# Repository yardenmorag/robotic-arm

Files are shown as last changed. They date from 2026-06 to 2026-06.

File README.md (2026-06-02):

# 7-Servo 3D-Printed Robotic Arm

A custom-built robotic arm designed, 3D-printed, wired, and programmed as a hands-on robotics and mechatronics project.
The arm is controlled by an **ESP32** using a **PCA9685 16-channel PWM servo driver**. It uses seven servo motors to control the base, arm segments, wrist, and gripper.

## Project Overview

The goal of this project is to build a lightweight robotic arm capable of controlled joint movement and eventually position-based control using forward and inverse kinematics.
This project combines:

* Mechanical design and 3D printing
* Servo motor actuation
* ESP32 embedded control
* External power distribution
* Multi-joint motion control
* Future kinematics and simulation development

## Features

* 7 servo-controlled joints
* 3D-printed mechanical structure
* ESP32-based control system
* PCA9685 PWM servo driver for stable multi-servo control
* External 5 V power supply for the motors
* Smooth servo movement implementation
* Adjustable joint positions through code
* Designed for future inverse kinematics control

## Degrees of Freedom

The robotic arm includes the following controlled movements:

| Joint | Function | Servo Motor |
| --- | --- | --- |
| Base | Rotates the entire arm | DS3225 |
| Lower Arm | Lifts the lower arm from the base | DS3225 |
| Elbow | Controls elbow lifting motion | MG996R |
| Upper Arm | Lifts the upper arm segment | MG996R |
| Wrist Pitch | Moves the wrist up and down | MG90S |
| Wrist Roll  | Rotates the wrist | MG90S |
| Gripper | Opens and closes the gripper | MG90S |

## Hardware

### Electronics

| Component | Description |
| --- | --- |
| ESP32 | Main microcontroller |
| PCA9685 | 16-channel PWM servo driver |
| Mean Well LRS-75-5 | External 5 V power supply |
| DS3225 Servo ×2 | High-torque servos for the heavier lower joints |
| MG996R Servo ×2 | Medium/high-torque servos for the arm joints |
| MG90S Servo ×3 | Small servos for the wrist and gripper |

### Mechanical Parts

* Custom 3D-printed robotic arm structure
* 3D-printed arm links
* 3D-printed wrist assembly
* 3D-printed gripper
* Servo mounting brackets and joint connectors

## Servo Channel Mapping

The PCA9685 channels are mapped as follows:

| PCA9685 Channel | Joint |
| --- | --- |
| 0 | Base rotation |
| 1 | Lower arm lift |
| 2 | Elbow lift |
| 3 | Upper arm lift |
| 4 | Wrist pitch |
| 5 | Wrist roll |
| 6 | Gripper open/close |

Example mapping in code:

```cpp
const int baseChannel = 0;
const int lowerArmChannel = 1;
const int elbowChannel = 2;
const int upperArmChannel = 3;
const int wristPitchChannel = 4;
const int wristRollChannel = 5;
const int gripperChannel = 6;
```

## Wiring Overview

### PCA9685 to ESP32

| PCA9685 Pin | ESP32 Pin |
| --- | --- |
| SDA | GPIO 21 |
| SCL | GPIO 22 |
| GND | GND |
| VCC | ESP32 logic power |

### Servo Power

The servos are powered using an external 5 V power supply rather than directly from the ESP32.

Important wiring notes:

* The servo power supply is connected to the PCA9685 `V+` terminal.
* The ESP32 ground and external power supply ground must be connected together.
* The ESP32 should not directly power all of the servos.
* High-torque servos can draw significant current, especially under load.

## Software

The arm is controlled using Arduino-compatible C++ code running on the ESP32.

### Main Libraries

* `Wire.h`
* `Adafruit_PWMServoDriver.h`

### Control Method

The PCA9685 board generates PWM signals for each servo. Joint positions are controlled by sending target angles that are converted into PWM pulse values.

The software includes smooth movement behavior so that the servos move gradually toward their target positions instead of instantly jumping between angles.

## Example Starting Pose

An example initial joint pose used during development:

```cpp
int startPose[] = {
    95,  // Base
    0,   // Lower arm
    0,   // Elbow
    0,   // Upper arm
    90,  // Wrist pitch
    90,  // Wrist roll
    90   // Gripper
};
```

Actual safe angle ranges may vary depending on the mechanical design and servo installation orientation.

## Project Structure

```text
robotic-arm/
├── code/                # ESP32 / Arduino control code
├── cad/                 # 3D models and mechanical design files
├── images/              # Project photos and diagrams
├── simulation/          # Future kinematics or MATLAB simulation files
└── README.md
```

The repository structure can be adjusted depending on the files included in the project.

## Current Status

Completed:

* Mechanical arm design and assembly
* 3D-printed structure
* Servo installation
* ESP32 and PCA9685 control setup
* External servo power system
* Basic multi-joint movement
* Smooth servo motion testing

In development:

* Joint calibration and motion refinement
* Improved torque and mechanical stability
* Forward kinematics
* Inverse kinematics
* Simulation-based control
* Position-based end-effector movement

## Challenges Encountered

During development, several practical robotics challenges were explored:

* Providing enough torque for the heavier arm joints
* Reducing servo jitter at the end of movements
* Powering multiple servos safely
* Maintaining a common electrical ground between the controller and power supply
* Matching servo movement directions with the mechanical design
* Planning the transition from direct joint control to inverse kinematics

## Future Improvements

Planned improvements include:

* Implementing forward kinematics
* Implementing inverse kinematics for XYZ position control
* Integrating a simulation model of the arm
* Improving the mechanical rigidity of the joints
* Reducing play and vibration in the printed structure
* Adding manual control through a joystick or graphical interface
* Developing basic pick-and-place movement sequences

## Images and Demonstration

Add project images or videos here once available.

Example:

```md
![Robotic Arm Assembly](images/robotic-arm.jpg)
```

A demonstration video can also be linked here in the future.

## Learning Goals

This project was built as part of a personal learning journey in robotics and mechanical engineering. It provides practical experience in:

* Mechanical CAD design
* 3D printing
* Servo motor selection
* Embedded programming
* Power electronics and wiring
* Multi-joint robotics
* Robotic arm kinematics

## Author

**Yarden Morag**

Mechanical Engineering Student
Interested in robotics, mechatronics, and biomimetic mechanical design.

## License

This project is currently intended for educational and personal development purposes.

A formal open-source license can be added in the future.

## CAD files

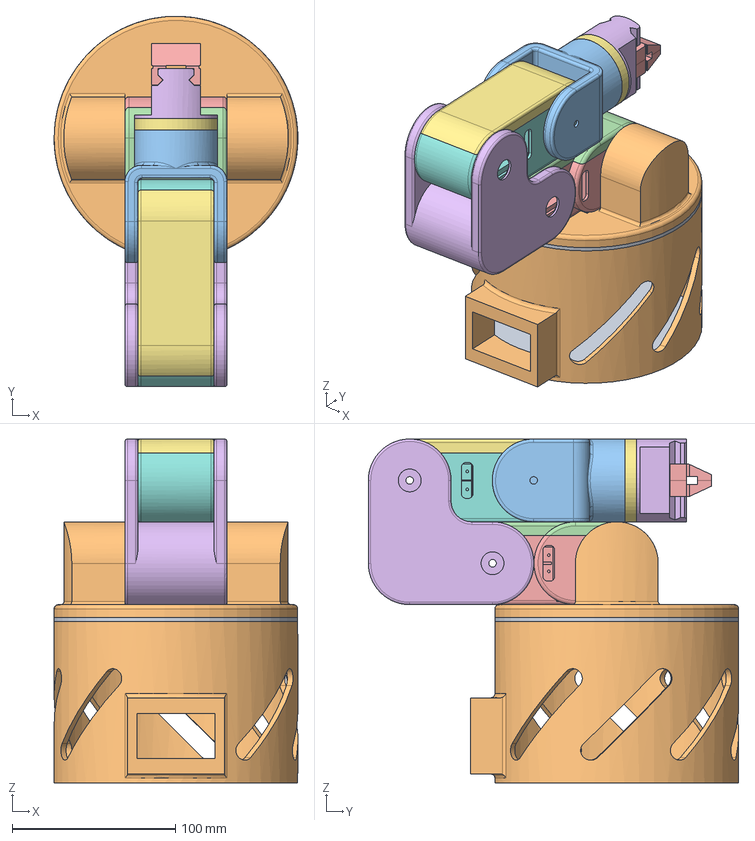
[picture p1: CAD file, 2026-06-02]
CAD files/fusion 360/Mark 1 Assembly.step
149.4 x 226.9 x 210.8 mm

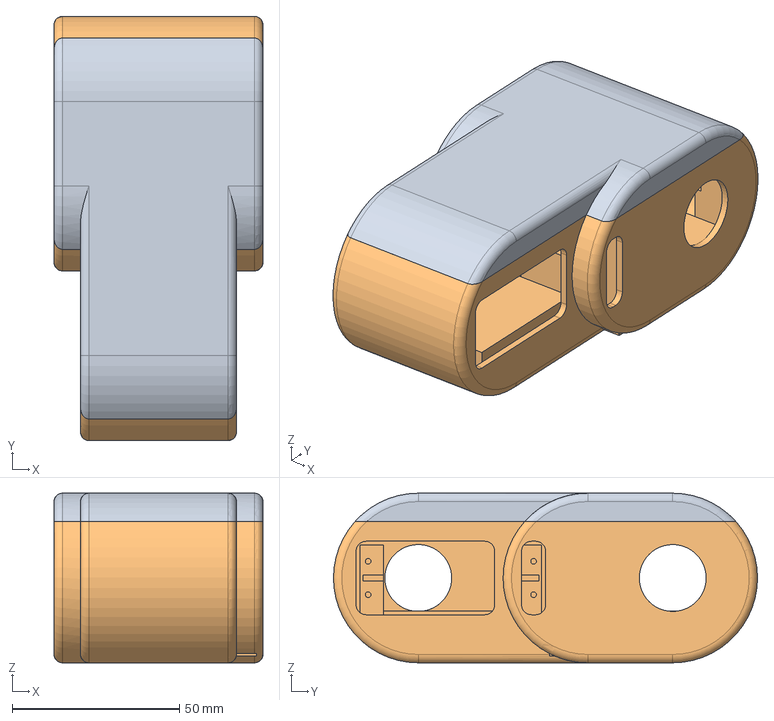
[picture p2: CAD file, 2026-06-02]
CAD files/fusion 360/Lower arm.step
62.5 x 126.9 x 50.8 mm

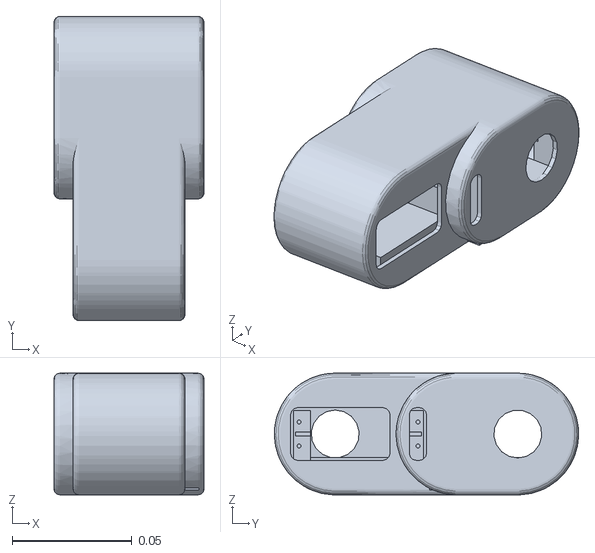
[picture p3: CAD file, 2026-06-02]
SImulation/URDF_mesh3/meshes/link_2.STL
0.0625 x 0.127 x 0.0507

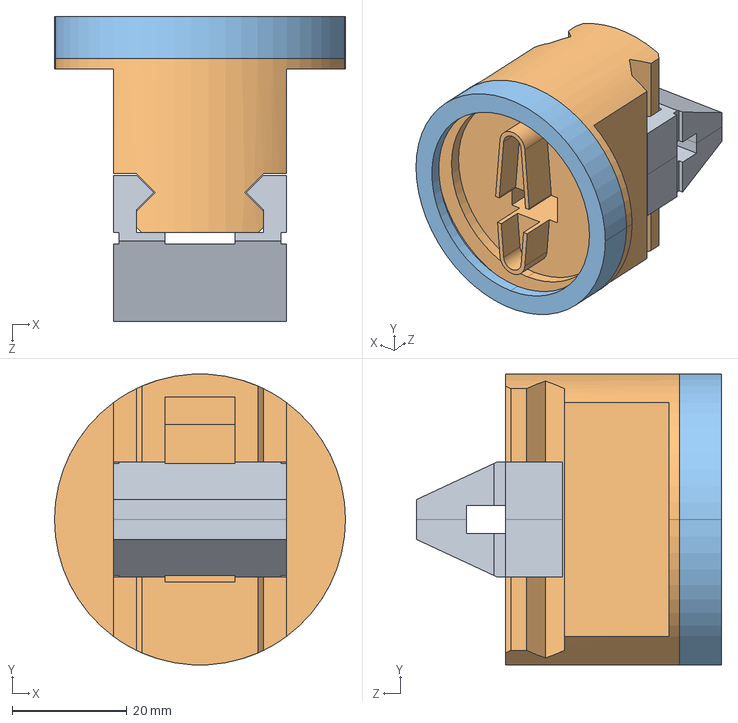
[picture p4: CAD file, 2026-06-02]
SImulation/xml files/Gripper part_Default_sldprt.STEP
50.8 x 50.7 x 53.2 mm

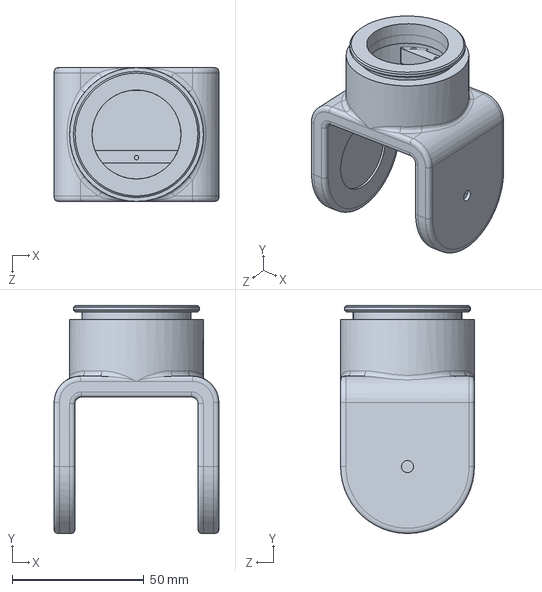
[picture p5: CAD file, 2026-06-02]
CAD files/solidworks/Upper joint.SLDPRT
62.5 x 86.5 x 50.8 mm

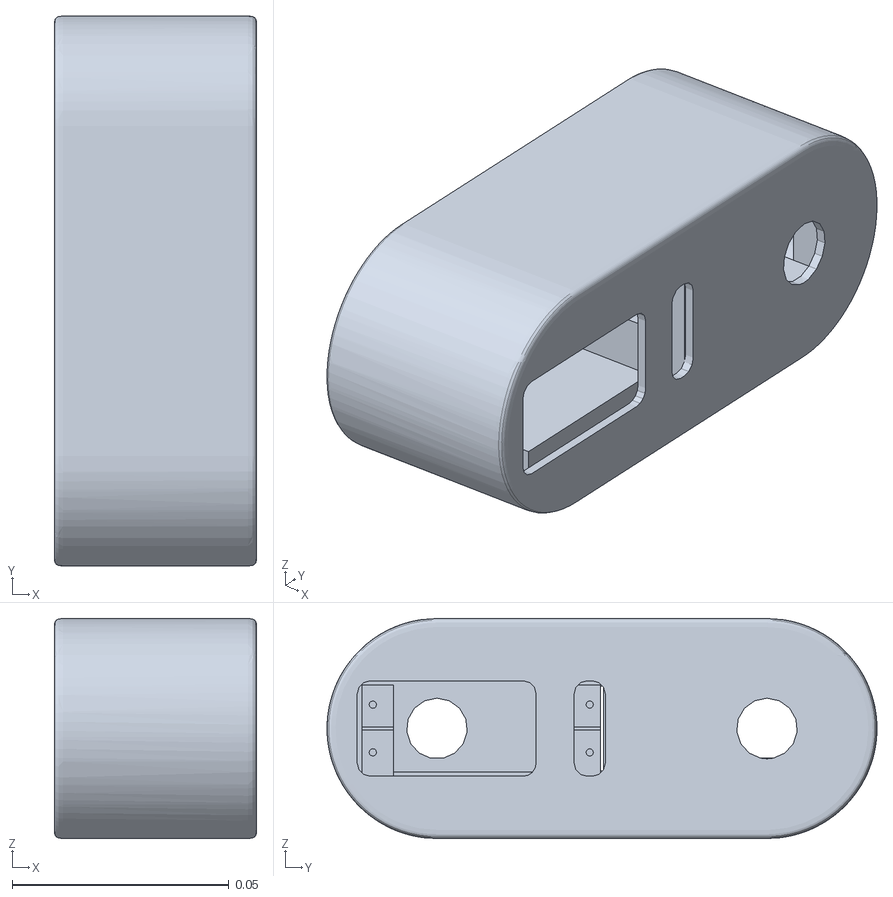
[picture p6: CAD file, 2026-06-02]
SImulation/URDF_mesh3/meshes/link_4.STL
0.0467 x 0.127 x 0.0507

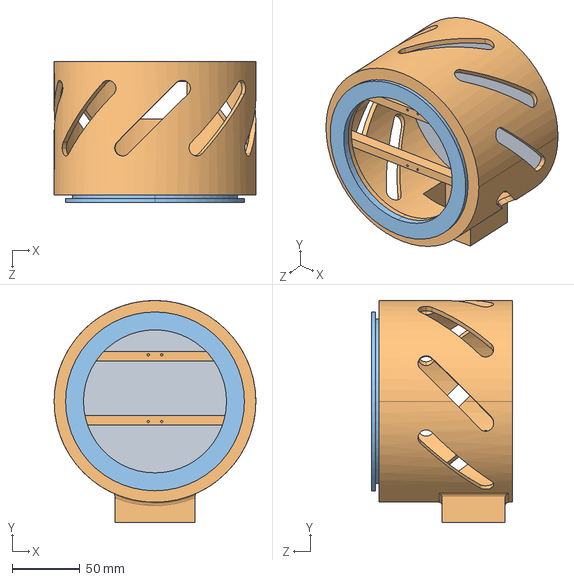
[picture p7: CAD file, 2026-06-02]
SImulation/xml files/Base frame_Default_sldprt.STEP
149.4 x 164.4 x 104.6 mm

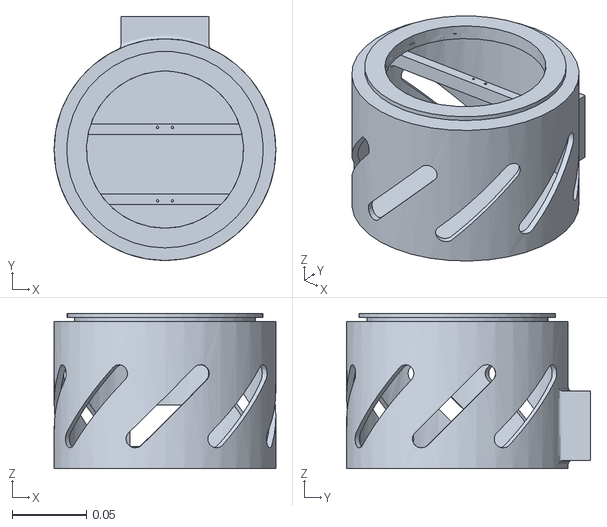
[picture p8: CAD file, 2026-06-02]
SImulation/URDF_mesh3/meshes/base_link.STL
0.149 x 0.164 x 0.105

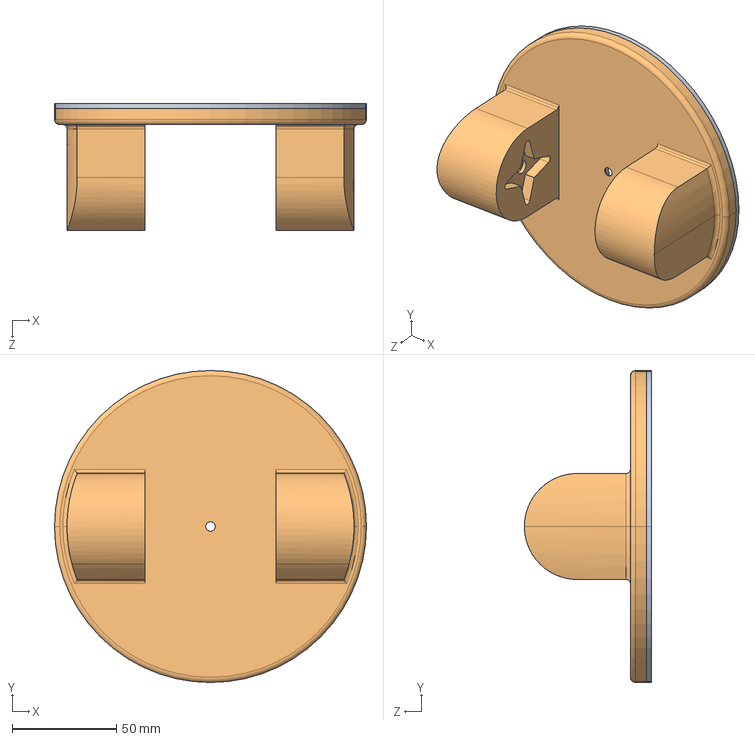
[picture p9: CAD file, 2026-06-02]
SImulation/xml files/Base rotator_Default_sldprt.STEP
149.4 x 149.4 x 60.9 mm

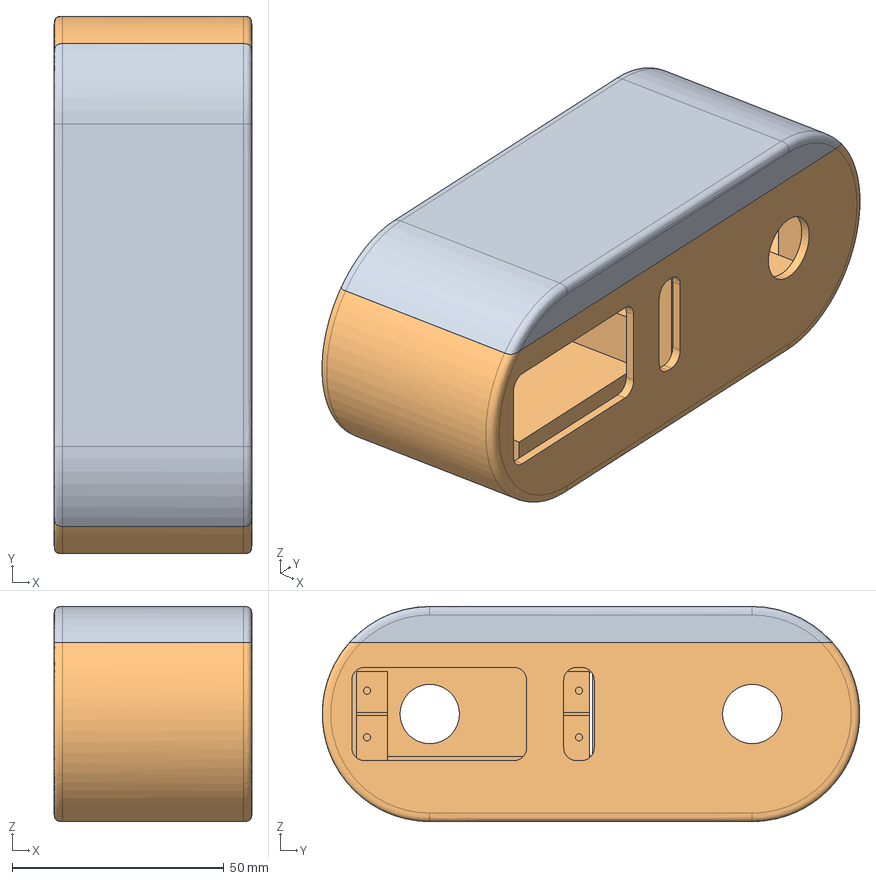
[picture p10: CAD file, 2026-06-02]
CAD files/fusion 360/Upper arm.step
46.7 x 126.9 x 50.8 mm

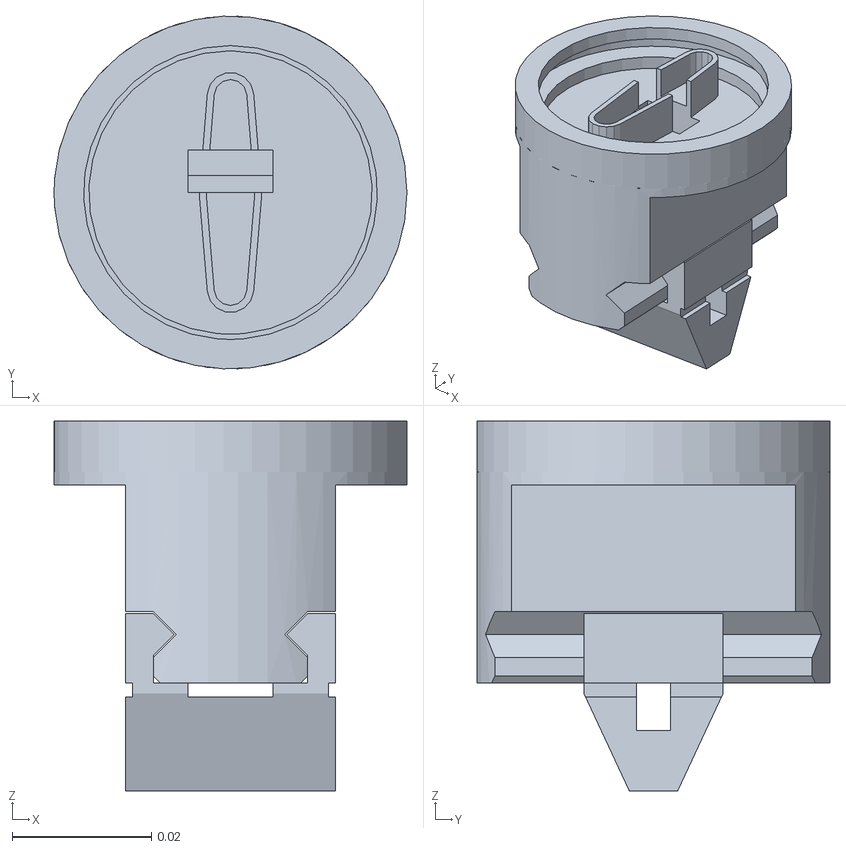
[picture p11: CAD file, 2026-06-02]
SImulation/URDF_mesh3/meshes/link_6.STL
0.0507 x 0.0507 x 0.0532

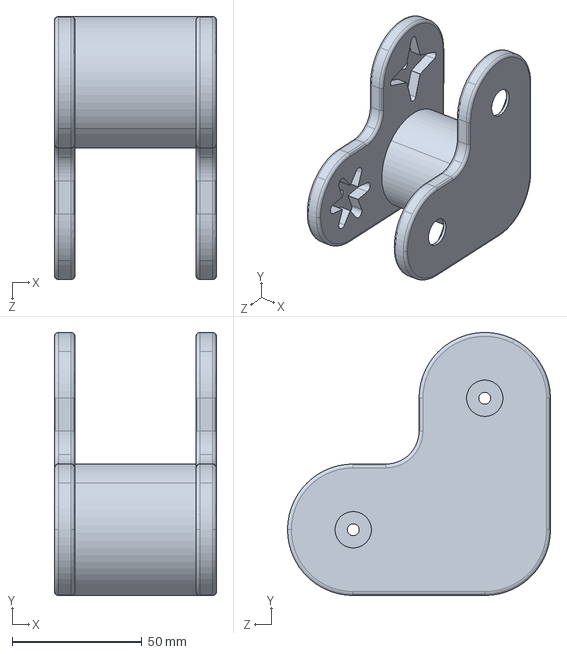
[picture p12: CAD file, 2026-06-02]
SImulation/xml files/Lower joint_Default_sldprt.STEP
62.5 x 101.5 x 101.5 mm

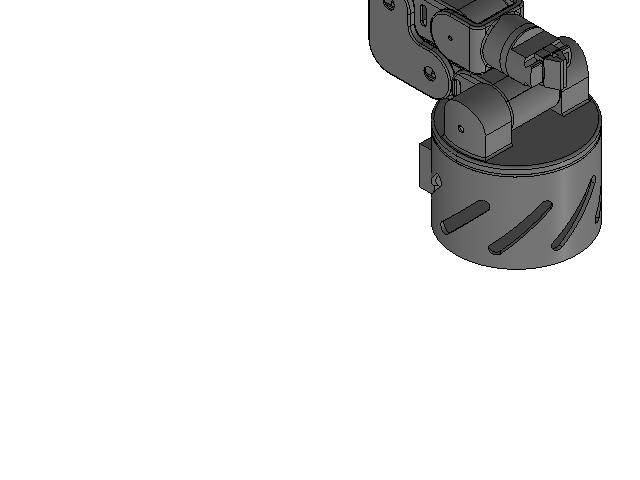
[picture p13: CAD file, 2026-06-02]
CAD files/solidworks/Robot assembly.SLDASM
Base frame
Base rotator
Lower arm
Lower joint
Upper arm
Upper joint
Gripper part

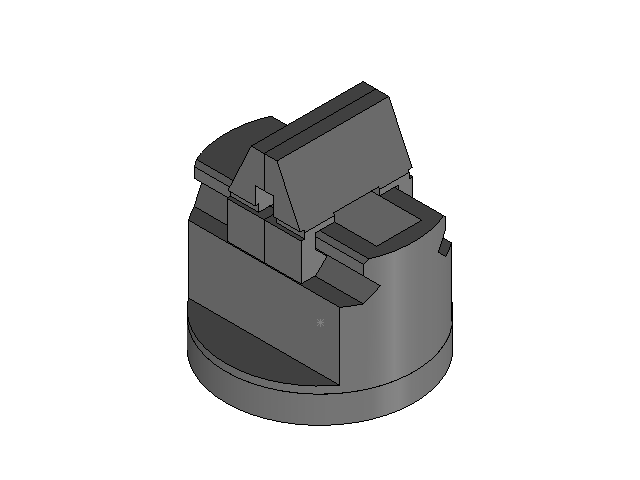
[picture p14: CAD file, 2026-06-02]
CAD files/solidworks/Gripper assmebly.SLDASM
2025-07-12-18-57-27-273.step
2025-07-12-18-57-29-992.step
eBom-FreeParts.step

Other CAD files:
CAD files/fusion 360/Gripper.step
CAD files/fusion 360/Base frame.step
CAD files/solidworks/Gripper part.SLDPRT
CAD files/fusion 360/Base rotator.step
CAD files/fusion 360/Lower joint.step
CAD files/fusion 360/Upper joint.step
CAD files/solidworks/Base frame.SLDPRT
CAD files/solidworks/Base rotator.SLDPRT
CAD files/solidworks/Lower arm.SLDPRT
CAD files/solidworks/Lower joint.SLDPRT
CAD files/solidworks/Upper arm.SLDPRT
SImulation/URDF_mesh3/meshes/link_1.STL
SImulation/URDF_mesh3/meshes/link_3.STL
SImulation/URDF_mesh3/meshes/link_5.STL
SImulation/xml files/Lower arm_Default_sldprt.STEP
SImulation/xml files/Upper arm_Default_sldprt.STEP
SImulation/xml files/Upper joint_Default_sldprt.STEP

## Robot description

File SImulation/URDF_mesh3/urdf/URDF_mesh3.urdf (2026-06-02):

<?xml version="1.0" encoding="utf-8"?>
<!-- This URDF was automatically created by SolidWorks to URDF Exporter! Originally created by Stephen Brawner (brawner@gmail.com) 
     Commit Version: 1.6.0-4-g7f85cfe  Build Version: 1.6.7995.38578
     For more information, please see http://wiki.ros.org/sw_urdf_exporter -->
<robot name="URDF_mesh3">
  <link name="base_link">
    <inertial>
      <origin xyz="-2.88841529450125E-05 0.00680637713324165 0.0542195174122674" rpy="0 0 0" />
      <mass value="0.276769434491233" />
      <inertia ixx="0.000920049908931992" ixy="4.47962690896385E-07" ixz="8.47165923723122E-07" iyy="0.000798308663008452" iyz="5.72343861467879E-05" izz="0.00126720597801514" />
    </inertial>
    <visual>
      <origin xyz="0 0 0" rpy="0 0 0" />
      <geometry>
        <mesh filename="package://URDF_mesh3/meshes/base_link.STL" />
      </geometry>
      <material name="">
        <color rgba="0.627450980392157 0.627450980392157 0.627450980392157 1" />
      </material>
    </visual>
    <collision>
      <origin xyz="0 0 0" rpy="0 0 0" />
      <geometry>
        <mesh filename="package://URDF_mesh3/meshes/base_link.STL" />
      </geometry>
    </collision>
  </link>
  <link name="link_1">
    <inertial>
      <origin xyz="-0.0010669 -5.4441E-06 0.016145" rpy="0 0 0" />
      <mass value="0.10166" />
      <inertia ixx="0.0001764" ixy="2.5396E-10" ixz="1.8796E-06" iyy="0.00023841" iyz="-8.9944E-09" izz="0.00036361" />
    </inertial>
    <visual>
      <origin xyz="0 0 0" rpy="0 0 0" />
      <geometry>
        <mesh filename="package://URDF_mesh3/meshes/link_1.STL" />
      </geometry>
      <material name="">
        <color rgba="0.62745 0.62745 0.62745 1" />
      </material>
    </visual>
    <collision>
      <origin xyz="0 0 0" rpy="0 0 0" />
      <geometry>
        <mesh filename="package://URDF_mesh3/meshes/link_1.STL" />
      </geometry>
    </collision>
  </link>
  <joint name="joint_1" type="revolute">
    <origin xyz="0 0 0.09905" rpy="0 0 0" />
    <parent link="base_link" />
    <child link="link_1" />
    <axis xyz="0 0 1" />
    <limit lower="-1.57" upper="1.57" effort="10" velocity="100" />
  </joint>
  <link name="link_2">
    <inertial>
      <origin xyz="0.002007 -0.036338 -0.0064654" rpy="0 0 0" />
      <mass value="0.10565" />
      <inertia ixx="0.00013506" ixy="-1.2634E-05" ixz="2.7537E-07" iyy="4.4035E-05" iyz="-1.7264E-07" izz="0.00015959" />
    </inertial>
    <visual>
      <origin xyz="0 0 0" rpy="0 0 0" />
      <geometry>
        <mesh filename="package://URDF_mesh3/meshes/link_2.STL" />
      </geometry>
      <material name="">
        <color rgba="0.62745 0.62745 0.62745 1" />
      </material>
    </visual>
    <collision>
      <origin xyz="0 0 0" rpy="0 0 0" />
      <geometry>
        <mesh filename="package://URDF_mesh3/meshes/link_2.STL" />
      </geometry>
    </collision>
  </link>
  <!-- UPDATED: joint_2 limits to negative range, keep axis as +X -->
  <joint name="joint_2" type="revolute">
    <origin xyz="0 0 0.035575" rpy="0 0 3.1416" />
    <parent link="link_1" />
    <child link="link_2" />
    <axis xyz="1 0 0" />
    <limit lower="-3.14" upper="0.0" effort="10" velocity="100" />
  </joint>
  <link name="link_3">
    <inertial>
      <origin xyz="-0.0021945 -0.037173 0.013431" rpy="0 0 0" />
      <mass value="0.056164" />
      <inertia ixx="8.1864E-05" ixy="1.5822E-06" ixz="1.3441E-06" iyy="7.6267E-05" iyz="1.0556E-05" izz="7.6463E-05" />
    </inertial>
    <visual>
      <origin xyz="0 0 0" rpy="0 0 0" />
      <geometry>
        <mesh filename="package://URDF_mesh3/meshes/link_3.STL" />
      </geometry>
      <material name="">
        <color rgba="0.62745 0.62745 0.62745 1" />
      </material>
    </visual>
    <collision>
      <origin xyz="0 0 0" rpy="0 0 0" />
      <geometry>
        <mesh filename="package://URDF_mesh3/meshes/link_3.STL" />
      </geometry>
    </collision>
  </link>
  <!-- UPDATED: joint_3 limits to negative range, keep axis as +X -->
  <joint name="joint_3" type="revolute">
    <origin xyz="0 -0.0761249999999974 0" rpy="0 0 0" />
    <parent link="link_2" />
    <child link="link_3" />
    <axis xyz="1 0 0" />
    <limit lower="-1.5708" upper="0.0" effort="10" velocity="100" />
  </joint>
  <link name="link_4">
    <inertial>
      <origin xyz="-9.93928394361599E-07 0.0380601973046595 -0.00704542972957761" rpy="0 0 0" />
      <mass value="0.0977593136694577" />
      <inertia ixx="0.00012422679121059" ixy="-7.57273613330422E-06" ixz="1.05703297903424E-09" iyy="3.1370702379211E-05" iyz="2.36067369751032E-09" izz="0.00013757045449995" />
    </inertial>
    <visual>
      <origin xyz="0 0 0" rpy="0 0 0" />
      <geometry>
        <mesh filename="package://URDF_mesh3/meshes/link_4.STL" />
      </geometry>
      <material name="">
        <color rgba="0.627450980392157 0.627450980392157 0.627450980392157 1" />
      </material>
    </visual>
    <collision>
      <origin xyz="0 0 0" rpy="0 0 0" />
      <geometry>
        <mesh filename="package://URDF_mesh3/meshes/link_4.STL" />
      </geometry>
    </collision>
  </link>
  <joint name="joint_4" type="revolute">
    <origin xyz="0 -0.0507499999999999 0.05075" rpy="0 0 0" />
    <parent link="link_3" />
    <child link="link_4" />
    <axis xyz="1 0 0" />
    <limit lower="0" upper="6.283" effort="10" velocity="100" />
  </joint>
  <link name="link_5">
    <inertial>
      <origin xyz="0.0011622446183474 0.0300159917617823 -0.00014861417811951" rpy="0 0 0" />
      <mass value="0.0308248485930793" />
      <inertia ixx="2.17151468738054E-05" ixy="9.46174930656814E-07" ixz="-6.76466170810024E-09" iyy="2.09317844598001E-05" iyz="7.53279506943715E-08" izz="2.76571581841984E-05" />
    </inertial>
    <visual>
      <origin xyz="0 0 0" rpy="0 0 0" />
      <geometry>
        <mesh filename="package://URDF_mesh3/meshes/link_5.STL" />
      </geometry>
      <material name="">
        <color rgba="0.627450980392157 0.627450980392157 0.627450980392157 1" />
      </material>
    </visual>
    <collision>
      <origin xyz="0 0 0" rpy="0 0 0" />
      <geometry>
        <mesh filename="package://URDF_mesh3/meshes/link_5.STL" />
      </geometry>
    </collision>
  </link>
  <joint name="joint_5" type="revolute">
    <origin xyz="0 0.0761250000168926 0" rpy="0 0 0" />
    <parent link="link_4" />
    <child link="link_5" />
    <axis xyz="1 0 0" />
    <limit lower="-1.57" upper="1.57" effort="10" velocity="100" />
  </joint>
  <link name="link_6">
    <inertial>
      <origin xyz="4.34874358745674E-13 0.00115067073632438 -0.022579968354949" rpy="0 0 0" />
      <mass value="0.0408091184402496" />
      <inertia ixx="1.03629622764239E-05" ixy="1.9860708475081E-17" ixz="2.2466219914749E-15" iyy="6.89840949583298E-06" iyz="2.46332338872545E-07" izz="1.1838330156667E-05" />
    </inertial>
    <visual>
      <origin xyz="0 0 0" rpy="0 0 0" />
      <geometry>
        <mesh filename="package://URDF_mesh3/meshes/link_6.STL" />
      </geometry>
      <material name="">
        <color rgba="0.627450980392157 0.627450980392157 0.627450980392157 1" />
      </material>
    </visual>
    <collision>
      <origin xyz="0 0 0" rpy="0 0 0" />
      <geometry>
        <mesh filename="package://URDF_mesh3/meshes/link_6.STL" />
      </geometry>
    </collision>
  </link>
  <joint name="joint_6" type="revolute">
    <origin xyz="0 0.055817 0" rpy="1.5708 1.5708 0" />
    <parent link="link_5" />
    <child link="link_6" />
    <axis xyz="0 0 1" />
    <limit lower="-1.57" upper="1.57" effort="10" velocity="100" />
  </joint>
</robot>

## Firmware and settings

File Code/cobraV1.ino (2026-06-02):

#include <Wire.h>
#include <Adafruit_PWMServoDriver.h>

Adafruit_PWMServoDriver robot = Adafruit_PWMServoDriver(); // Default I2C address 0x40

#define SERVOMIN  150  
#define SERVOMAX  600  

int angleToPulse(int angle) {
  return map(angle, 0, 180, SERVOMIN, SERVOMAX);
}

// Servo channels
int baseChannel = 0;
int lowerArmChannel_1 = 1;
int lowerArmChannel_2 = 2;
int upperArmChannel_1 = 3;
int upperArmChannel_2 = 4;
int wristChannel = 5;
int gripperChannel = 6;

const int startPos[7] = {95, 0, 0, 0, 90, 90, 90}; // starting position
int currentPos[7];  // track current positions

// Simple linear move for all servos together
void moveAllServos(const int targets[], int steps = 45, int stepDelay = 8) {  // <-- Faster (8ms)
  int start[7];
  for (int i = 0; i < 7; i++) start[i] = currentPos[i];

  for (int step = 1; step <= steps; step++) {
    for (int i = 0; i < 7; i++) {
      if (i == gripperChannel) continue; // keep gripper instant
      int newAngle = start[i] + (targets[i] - start[i]) * step / steps;
      robot.setPWM(i, 0, angleToPulse(newAngle));
    }
    delay(stepDelay);
  }

  // Gripper instantly at end
  robot.setPWM(gripperChannel, 0, angleToPulse(targets[gripperChannel]));

  // Save final positions
  for (int i = 0; i < 7; i++) currentPos[i] = targets[i];
}

void setup() {
  Serial.begin(115200);
  Wire.begin(21, 22);
  robot.begin();
  robot.setPWMFreq(50);
  delay(10);

  // Initialize current positions
  for (int i = 0; i < 7; i++) currentPos[i] = startPos[i];
}

void loop() {
  int randomPos[7] = {130, 20, 15, 40, 130, 0, 0};

  moveAllServos(startPos, 45, 8);   // Slightly faster to start
  delay(2000);
  moveAllServos(randomPos, 45, 8);  // Slightly faster to random
  delay(2000);
}
